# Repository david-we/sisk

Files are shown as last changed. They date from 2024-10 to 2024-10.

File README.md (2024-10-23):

# SiSK 
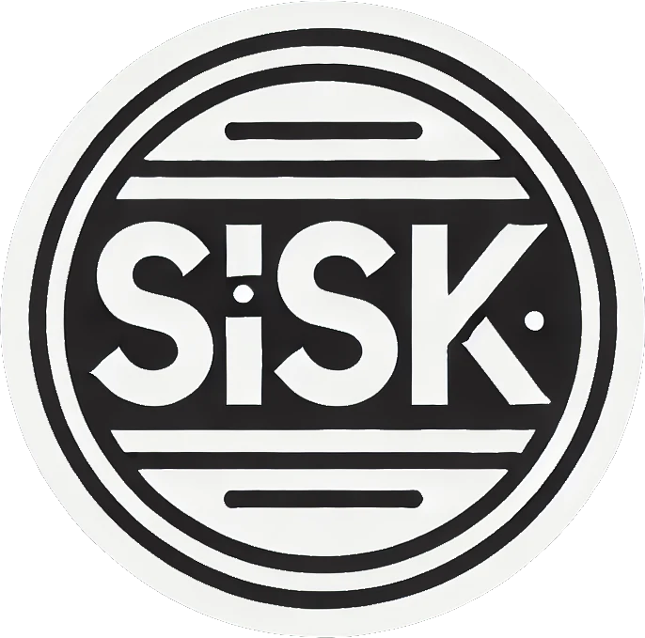
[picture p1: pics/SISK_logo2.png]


**THIS IS STILL WORK IN PROGRESS !**  

SiSK is a split keyboard with focus on standard staggered ISO Layout. it is an opportunity for those that do not want to jump on the ortholinear bandwagon, but still want to have the ergonomic advantages of a split keyboard. There will be a 60% version and a 65% Version of the PCB (which is already in the making). 

The plan is it starts as a base PCB which can then be easily used for DIY 3D-printed case designs. I am also planing to experiment with different case mounting techniques like top mount, sandwich mount, tray mount, gasket mount...

SiSK is meant as a wireless keyboard and my first prototype will use nice!nano v2 compatible Microcontroller boards and el cheapo 128x32 i2C displays for monitoring the battery...

## naming
**S**plit **I**SO **S**taggered **K**eyboard  
i know very ingenious :sweat_smile: but it was a very quick decision and AI created a logo that i liked, so its fine!

## features

- split
- ISO
- staggered
- wireless
- screw on wrist/palm wrest
- 128x32 OLED Display (I2C)
- 60% and 65% Version available
- first case will probably also use a foldable tenting solution (chinese mini Laptop stands)

### why?

I know there are similar keyboards out there, in fact there are also kits available that are in the same category. But still i was not satisfied with the existing solutions. Some where also hard to get in europe or had no ISO Layout. Another big point for me was the learning aspect, especially KiCAD and SMD soldering. AND i want a detachable solution for palm rests.

## pics

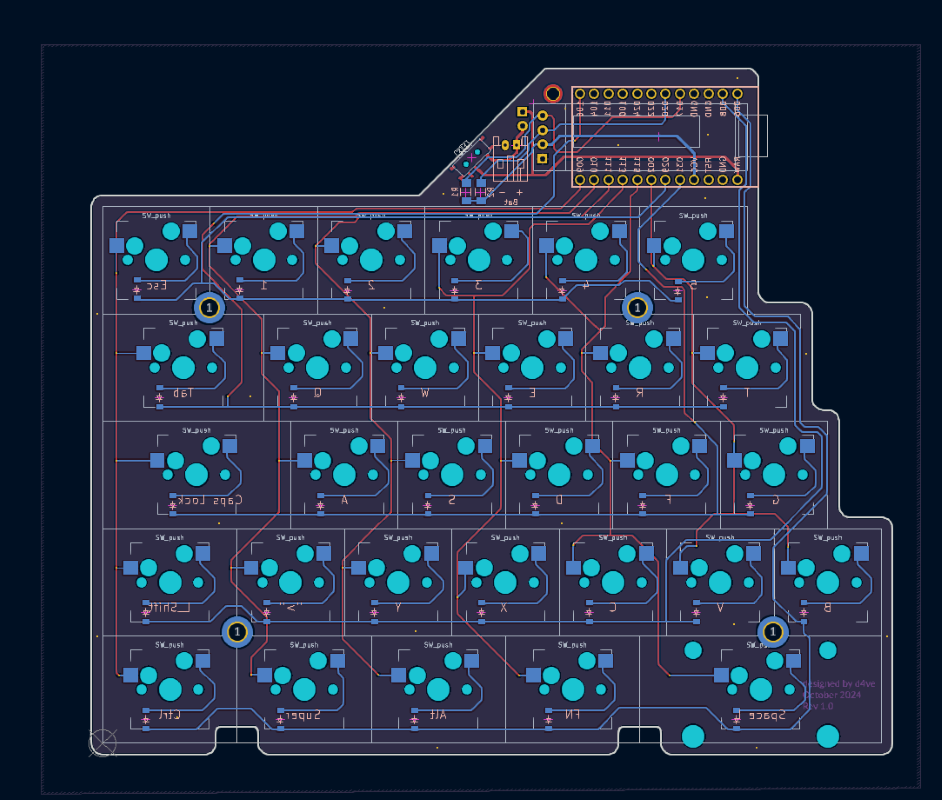
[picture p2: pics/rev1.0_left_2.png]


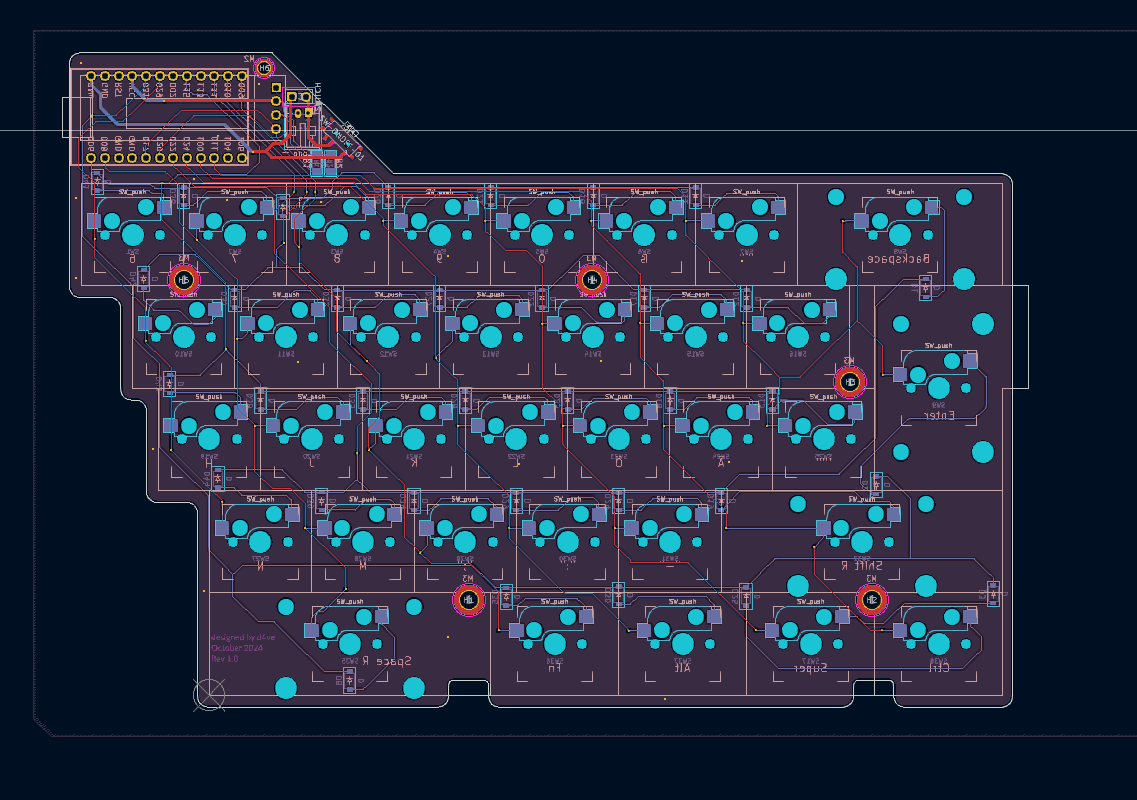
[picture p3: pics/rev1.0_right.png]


### history

last year i made this thing, which is kind of the predecessor of SiSK. But handwired and driven by a raspberry pi pico. It worked very well but the connector between the two halves sometimes looses contact. then i have to wobble around on the connector and it works again :P ... otherwise it worked flawless  

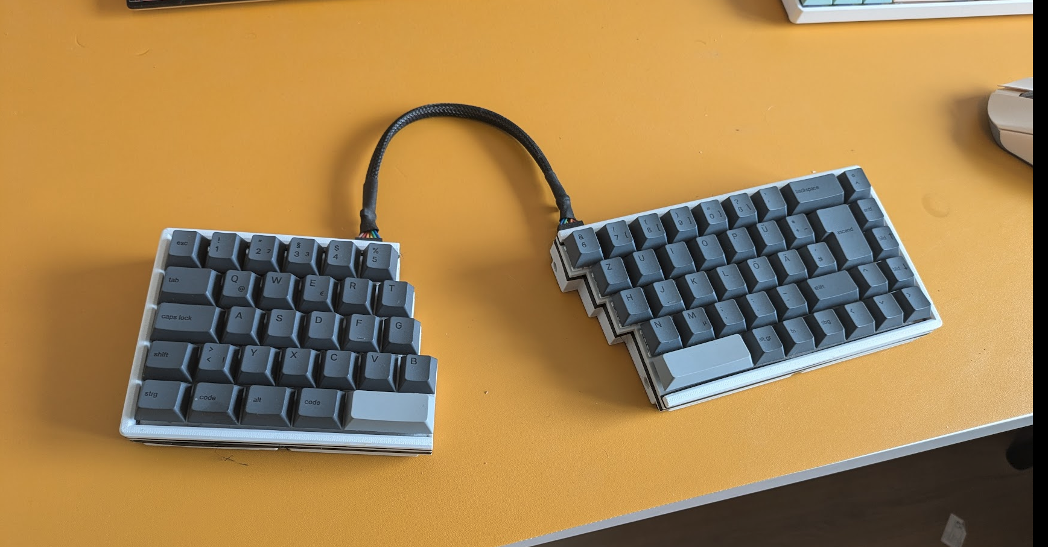
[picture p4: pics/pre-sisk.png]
sisk


## next steps

waiting for PCBs :) 

## ideas for future

- ANSI layout

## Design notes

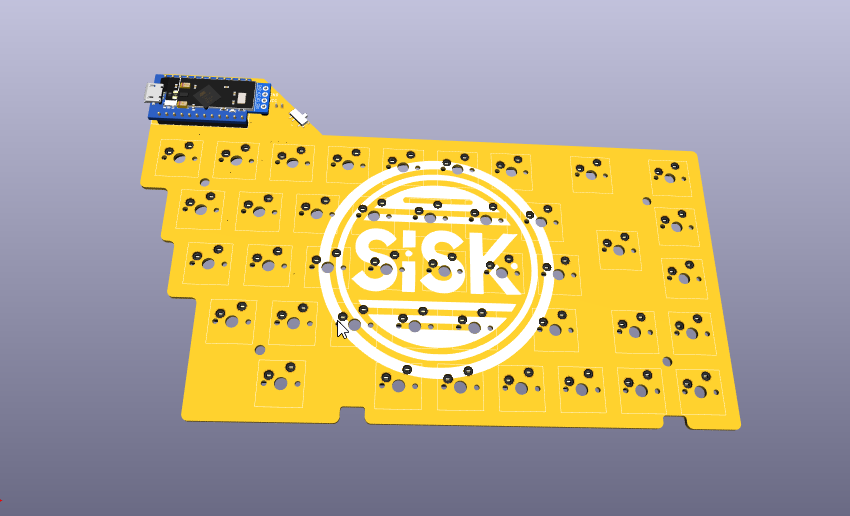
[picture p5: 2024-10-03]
pics/right_sisk_3d.png

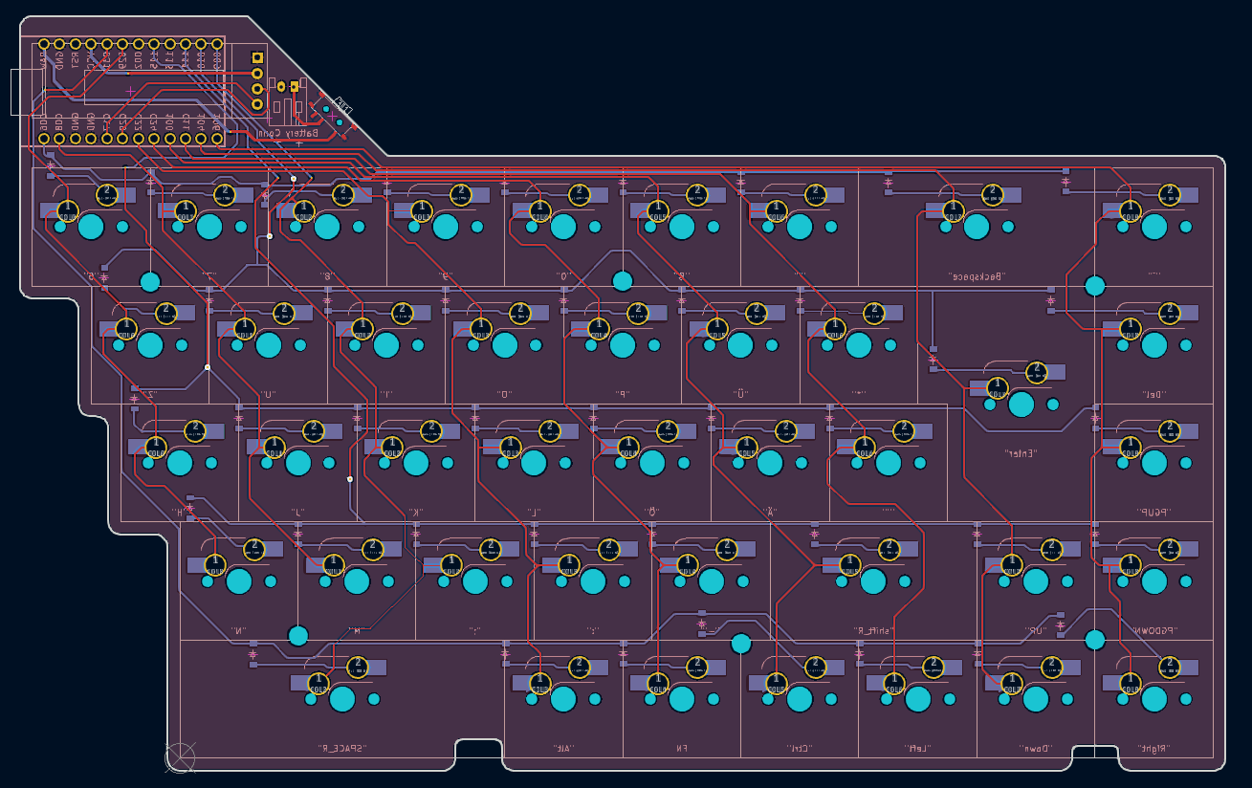
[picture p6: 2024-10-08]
pics/right_pcb_routing.png

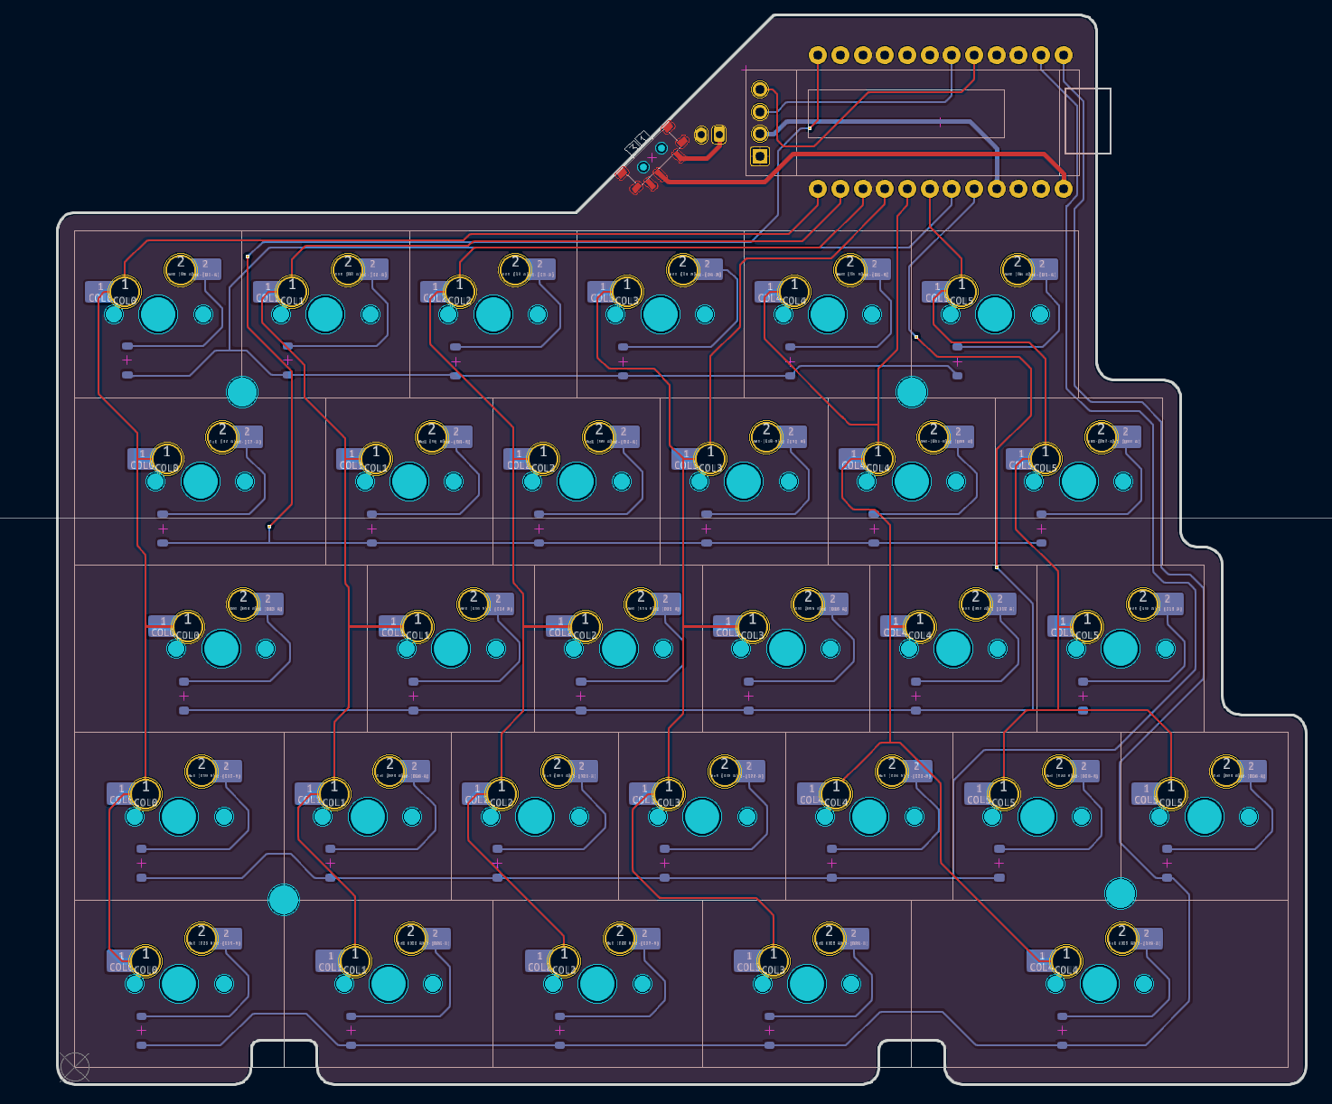
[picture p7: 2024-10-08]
pics/left_pcb_routing.PNG

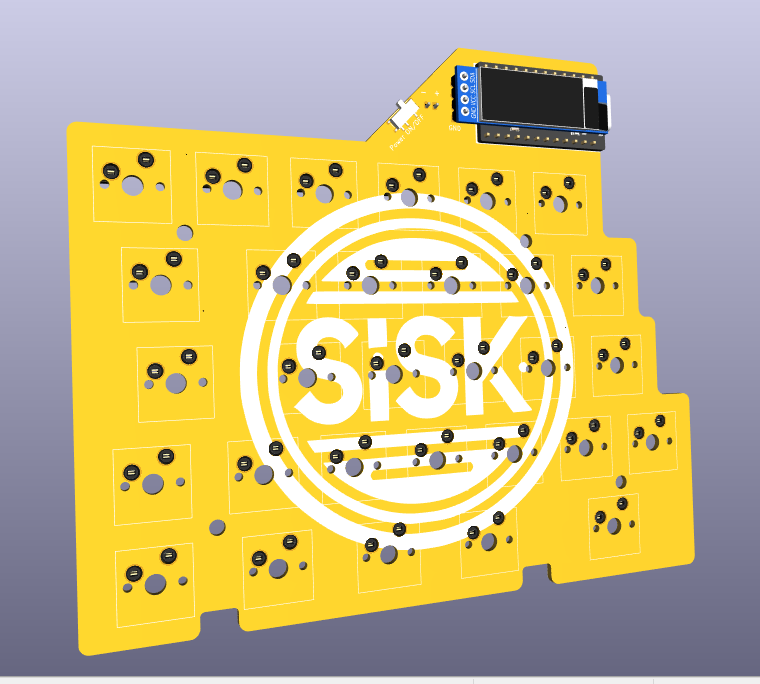
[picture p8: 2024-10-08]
pics/left_pcb_3d_front.PNG

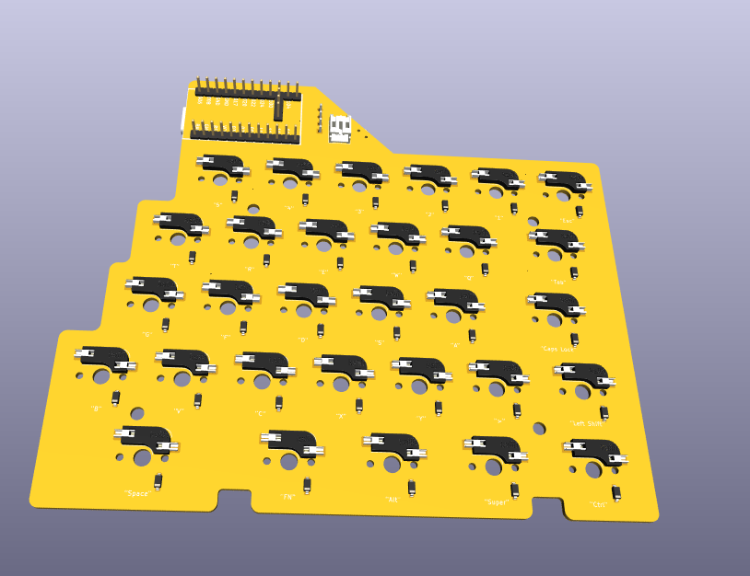
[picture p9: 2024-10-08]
pics/left_pcb_3d_back.PNG

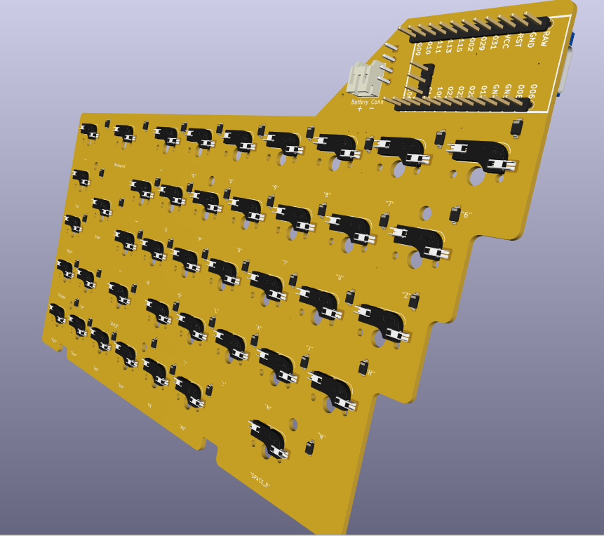
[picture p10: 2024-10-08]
pics/right_pcb_3d_back.PNG

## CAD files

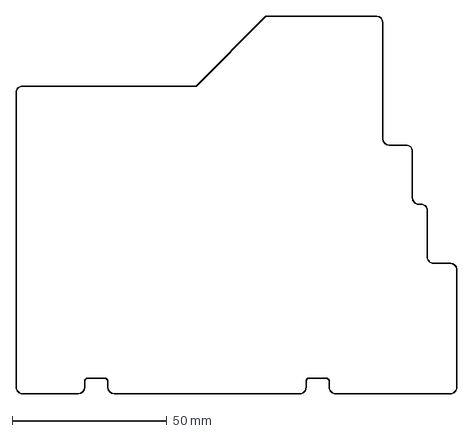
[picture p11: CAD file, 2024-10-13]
SISK_left/outline_left_w_cutouts2.dxf
142.1 x 121.7 mm

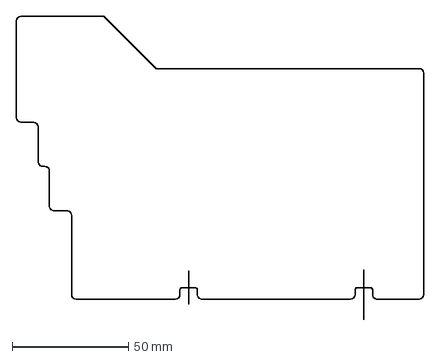
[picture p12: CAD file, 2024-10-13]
SISK_right_60/outline_right_w_cutouts_1mm.dxf
175.5 x 130.6 mm

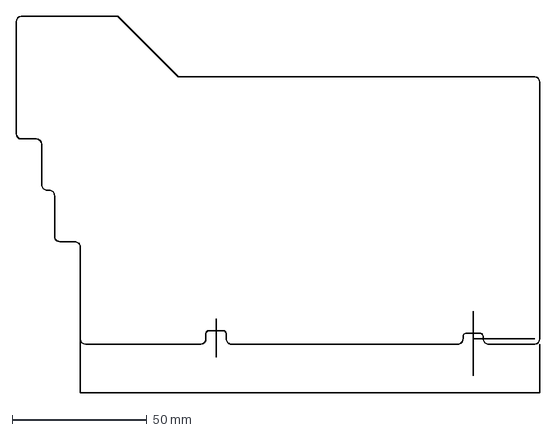
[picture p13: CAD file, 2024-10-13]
SISK_right_65/outline_right_w_cutouts2.dxf
194.5 x 139.8 mm

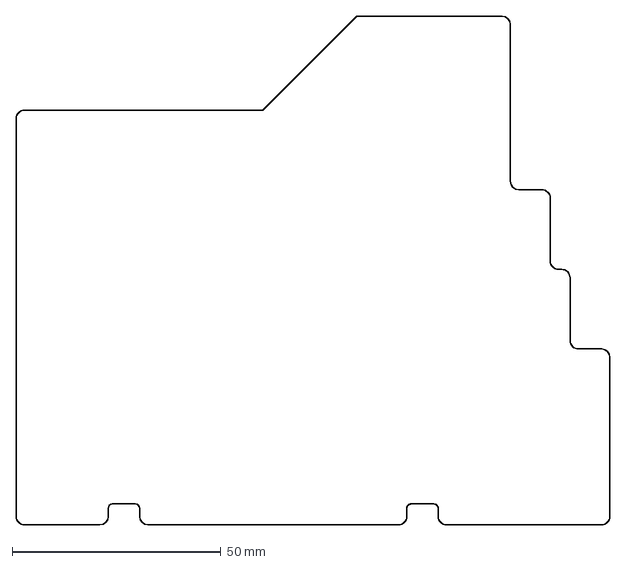
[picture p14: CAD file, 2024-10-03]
SISK_left/outline_left_w_cutouts.dxf
142.1 x 121.7 mm

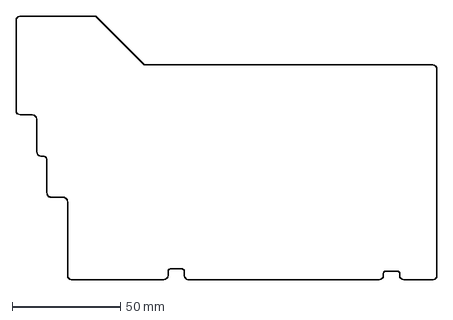
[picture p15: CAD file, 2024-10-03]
SISK_right_60/outline_right_w_cutouts.dxf
194.5 x 121.8 mm

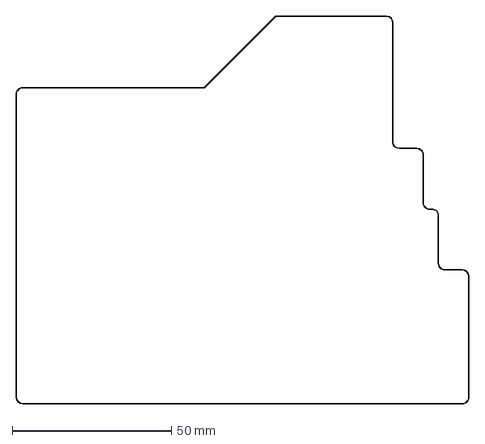
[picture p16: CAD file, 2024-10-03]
SISK_left/outline_left.dxf
142.1 x 121.7 mm

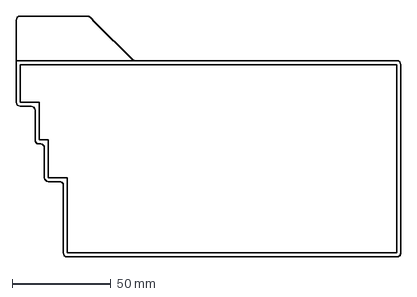
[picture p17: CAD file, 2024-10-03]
SISK_right_60/outline.dxf
194.5 x 121.8 mm

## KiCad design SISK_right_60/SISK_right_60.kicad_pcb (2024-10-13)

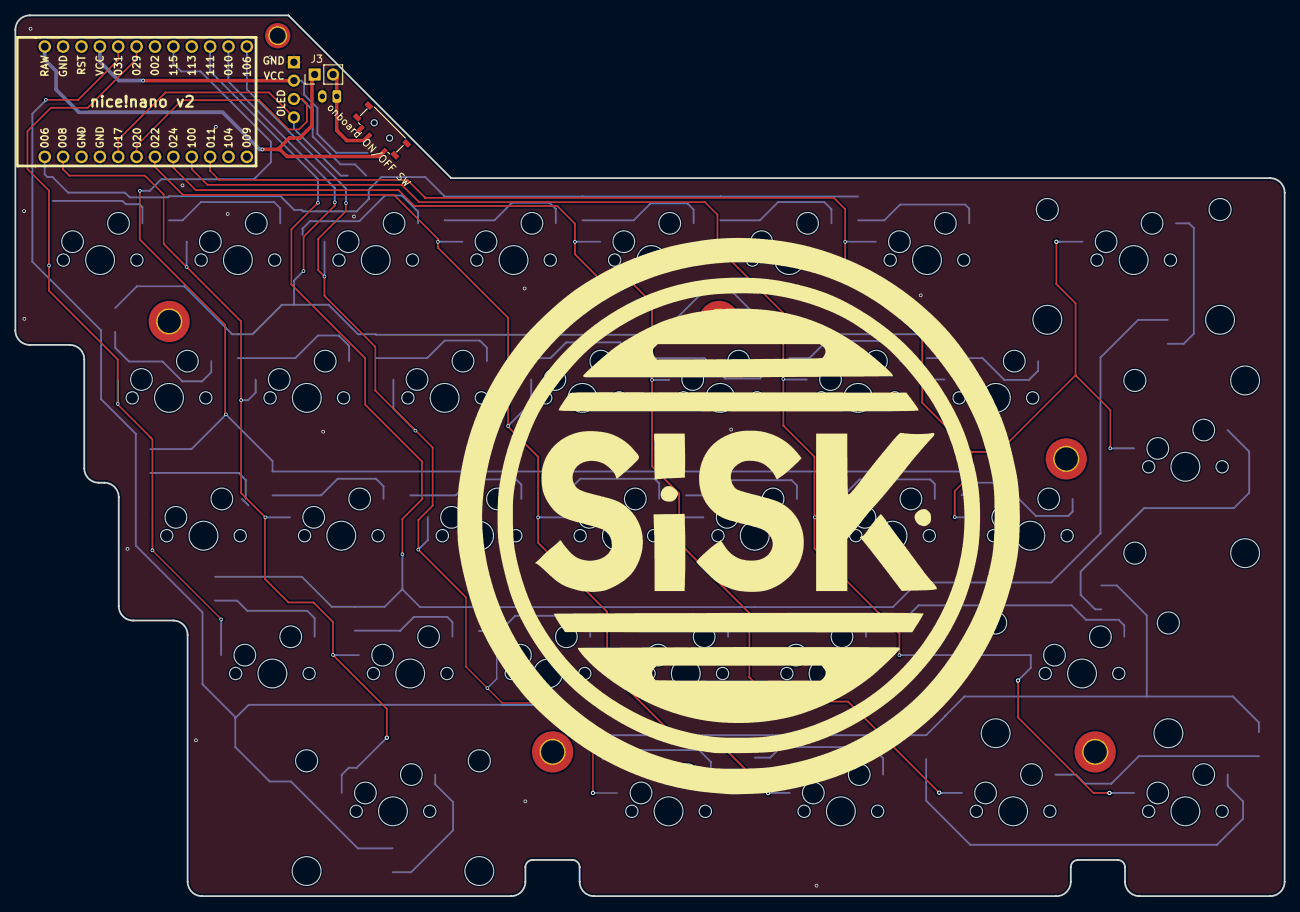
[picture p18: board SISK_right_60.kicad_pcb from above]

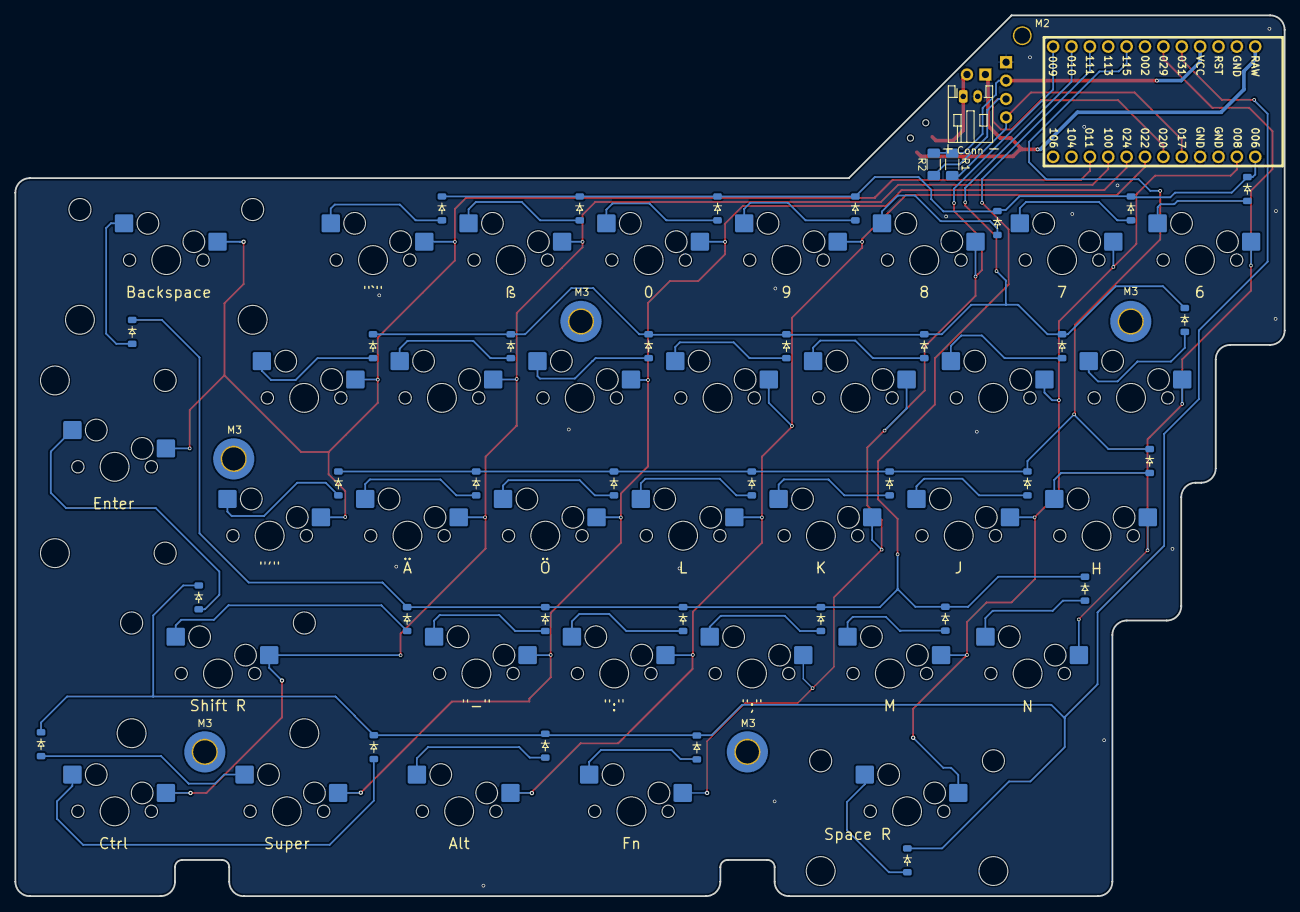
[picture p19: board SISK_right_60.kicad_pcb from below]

Board: 2 copper layers, 175.4 x 121.8 mm, 81 parts (71 on the bottom side), 52 nets.

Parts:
D1, D2, D3, D8, D11, D12, D13, D16, D17, D18, D19, D21, D22, D23, D24, D25, D26, D27, D28, D29, D30, D31, D32, D33, D34, D35, D36, D37, D38, D39, D41, D42, D43, D44: D; Diode_SOD-123
H1, H2, H3, H4, H5: M3; MountingHole_3.2mm_M3_ISO7380_Pad_TopBottom
H6: M2; MountingHole_2.2mm_M2_ISO7380_Pad_TopOnly
J1: OLED_128x32
J2: Conn; JST_PH_S2B-PH-K_1x02_P2.00mm_Horizontal
J3: SWITCH; PinHeader_1x02_P2.54mm_Vertical
R1, R2: 5K; R_1206_3216Metric_Pad1.30x1.75mm_HandSolder
SW1, SW2, SW3, SW4, SW5, SW6, SW7, SW10, SW11, SW12, SW13, SW14, SW15, SW16, SW19, SW20, SW21, SW22, SW23, SW24, SW25, SW27, SW28, SW29, SW30, SW31: SW_push; MX-Hotswap-1U
SW8: SW_push; MX-Hotswap-2U
SW9: SW_push; MX-Hotswap-ISO
SW17, SW36, SW37, SW38: SW_push; MX-Hotswap-1.25U
SW32, SW35: SW_push; MX-Hotswap-2.75U
SW-ONOFF-01: Switch_MSK12C02
U1: Nice_Nano_V2; nice_nano

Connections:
+3,3V: J1.2 (VCC), R1.1, R2.1, U1.21 (3.3v)
+BATT: J2.1, J3.2, SW-ONOFF-01.2 (B)
+VDC: J3.1, SW-ONOFF-01.1 (A), U1.24 (B+)
/COL0: SW1.1, SW10.1, SW19.1, SW27.1, U1.19 (20)
/COL1: SW2.1, SW11.1, SW20.1, SW28.1, SW35.1, U1.2 (0)
/COL2: SW3.1, SW12.1, SW21.1, SW29.1, SW36.1, U1.13 (10)
/COL3: SW4.1, SW13.1, SW22.1, SW30.1, SW37.1, U1.7 (4)
/COL4: SW5.1, SW14.1, SW17.1, SW23.1, SW31.1, U1.8 (5)
/COL5: SW6.1, SW15.1, SW24.1, SW32.1, SW38.1, U1.9 (6)
/COL6: SW7.1, SW8.1, SW9.1, SW16.1, SW25.1, U1.10 (7)
/ROW0: D11.1 (K), D16.1 (K), D21.1 (K), D26.1 (K), D31.1 (K), D36.1 (K), D41.1 (K), U1.1
/ROW1: D12.1 (K), D17.1 (K), D22.1 (K), D27.1 (K), D32.1 (K), D37.1 (K), D42.1 (K), U1.14 (16)
/ROW2: D13.1 (K), D18.1 (K), D23.1 (K), D28.1 (K), D33.1 (K), D38.1 (K), D43.1 (K), U1.17 (18)
/ROW3: D1.1 (K), D19.1 (K), D24.1 (K), D29.1 (K), D34.1 (K), D39.1 (K), D44.1 (K), U1.15 (14)
/ROW4: D2.1 (K), D3.1 (K), D8.1 (K), D25.1 (K), D30.1 (K), D35.1 (K), U1.20 (21)
/SCL: J1.3 (SCL), R2.2, U1.6 (3)
/SDA: J1.4 (SDA), R1.2, U1.5 (2)
GND: J1.1 (GND), J2.2, U1.3 (GND), U1.4 (GND), U1.23 (GND)
unnamed: D1.2 (A), SW8.2
unnamed: D2.2 (A), SW9.2
unnamed: D3.2 (A), SW17.2
unnamed: D8.2 (A), SW35.2
unnamed: D11.2 (A), SW7.2
unnamed: D12.2 (A), SW16.2
unnamed: D13.2 (A), SW25.2
unnamed: D16.2 (A), SW6.2
unnamed: D17.2 (A), SW15.2
unnamed: D18.2 (A), SW24.2
unnamed: D19.2 (A), SW32.2
unnamed: D21.2 (A), SW5.2
unnamed: D22.2 (A), SW14.2
unnamed: D23.2 (A), SW23.2
unnamed: D24.2 (A), SW31.2
unnamed: D25.2 (A), SW38.2
unnamed: D26.2 (A), SW4.2
unnamed: D27.2 (A), SW13.2
unnamed: D28.2 (A), SW22.2
unnamed: D29.2 (A), SW30.2
unnamed: D30.2 (A), SW37.2
unnamed: D31.2 (A), SW3.2
unnamed: D32.2 (A), SW12.2
unnamed: D33.2 (A), SW21.2
unnamed: D34.2 (A), SW29.2
unnamed: D35.2 (A), SW36.2
unnamed: D36.2 (A), SW2.2
unnamed: D37.2 (A), SW11.2
unnamed: D38.2 (A), SW20.2
unnamed: D39.2 (A), SW28.2
unnamed: D41.2 (A), SW1.2
unnamed: D42.2 (A), SW10.2
unnamed: D43.2 (A), SW19.2
unnamed: D44.2 (A), SW27.2

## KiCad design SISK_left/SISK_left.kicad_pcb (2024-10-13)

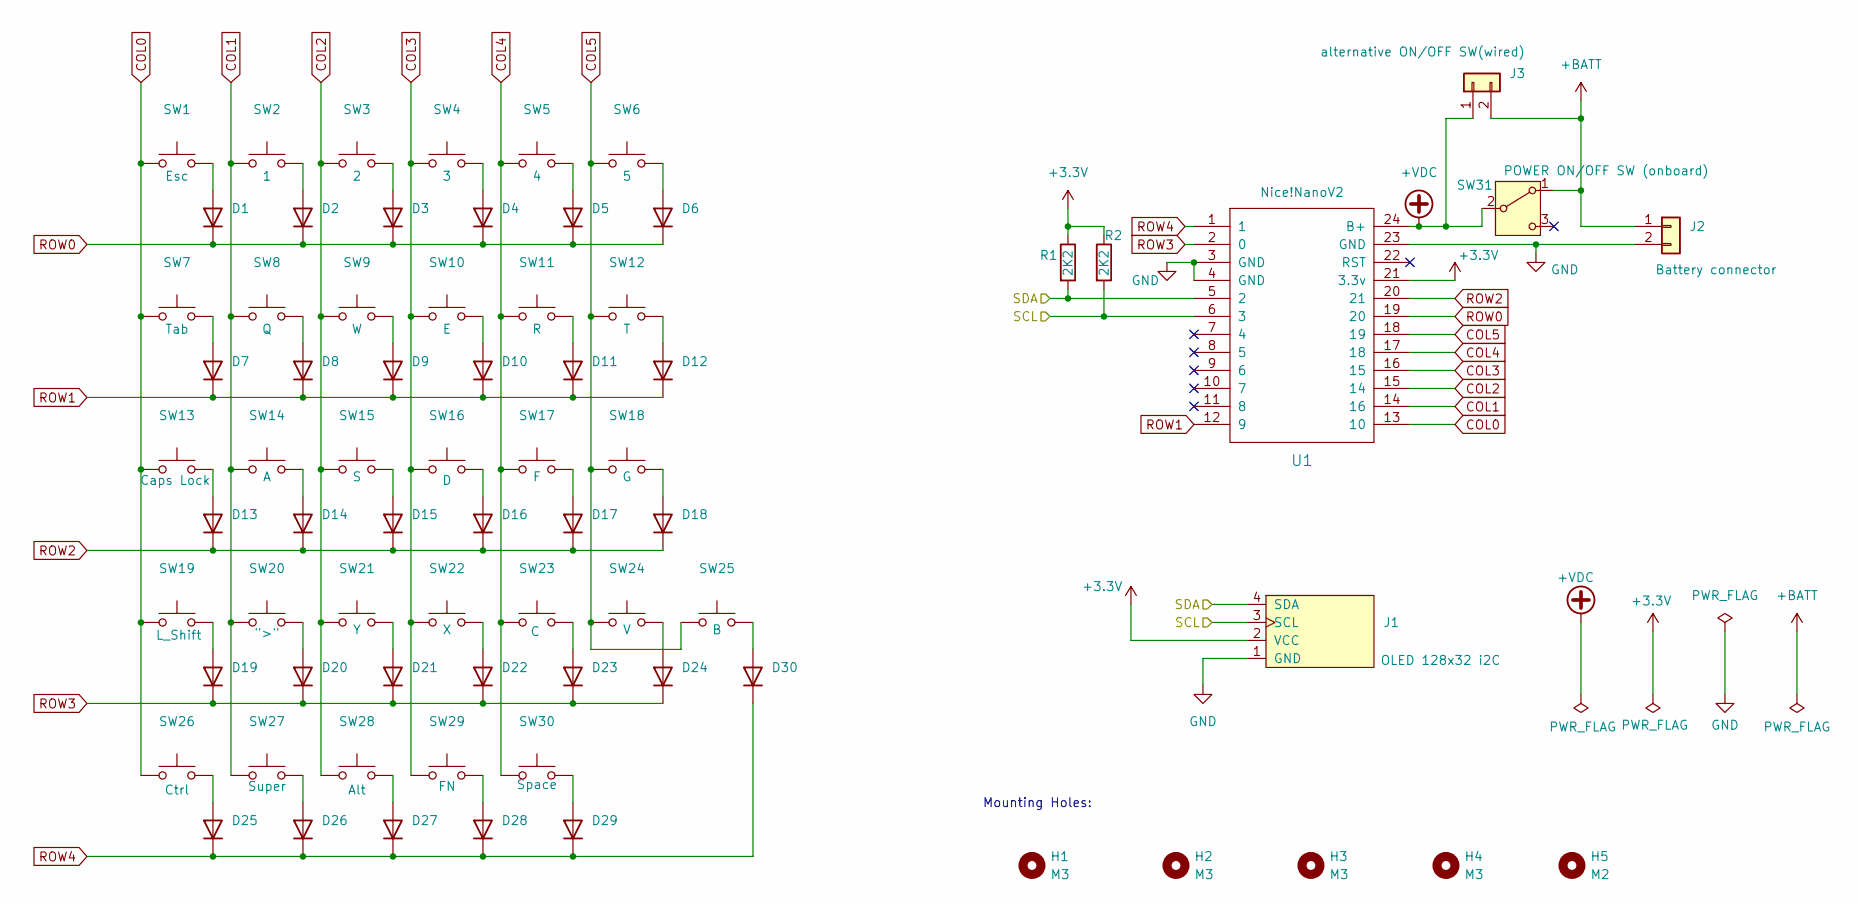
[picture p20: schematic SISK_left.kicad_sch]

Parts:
D1, D2, D3, D4, D5, D6, D7, D8, D9, D10, D11, D12, D13, D14, D15, D16, D17, D18, D19, D20, D21, D22, D23, D24, D25, D26, D27, D28, D29, D30: 1n4148; Diode_SOD-123; MPN 1N4148W
H1, H2, H3, H4: M3; MountingHole_3.2mm_M3_ISO7380_Pad_TopBottom
H5: M2; MountingHole_2.2mm_M2_ISO7380_Pad_TopOnly
J1: OLED_128x32; MPN OLED 128x32 i2C
J2: BAT; JST_PH_S2B-PH-K_1x02_P2.00mm_Horizontal; MPN S2B-PH-K-S(LF)(SN)
J3: CONN_ALT; PinHeader_1x02_P2.54mm_Vertical; MPN not known yet
R1, R2: 2K2; R_1206_3216Metric_Pad1.30x1.75mm_HandSolder; MPN RC1206JR-072K2L
SW1, SW2, SW3, SW4, SW5, SW6, SW8, SW9, SW10, SW11, SW12, SW14, SW15, SW16, SW17, SW18, SW20, SW21, SW22, SW23, SW24, SW25: SW_push; MX-Hotswap-1U; MPN CPG151101S11
SW7: SW_push; MX-Hotswap-1.5U; MPN CPG151101S11
SW13: SW_push; MX-Hotswap-1.75U; MPN CPG151101S11
SW19, SW26, SW27, SW28, SW29: SW_push; MX-Hotswap-1.25U; MPN CPG151101S11
SW30: SW_push; MX-Hotswap-2.25U; MPN CPG151101S11
SW31: SW_SPDT; Switch_MSK12C02; MPN MSK12C01
U1: Nice_Nano_V2; nice_nano; MPN nice!nano v2 or compatible

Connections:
+3.3V: J1.2 (VCC), R1.1, R2.1, U1.21 (3.3v)
+BATT: J2.1, J3.2, SW31.1 (A)
+VDC: J3.1, SW31.2 (B), U1.24 (B+)
/SCL: J1.3 (SCL), R2.2, U1.6 (3)
/SDA: J1.4 (SDA), R1.2, U1.5 (2)
COL0: SW1.1, SW7.1, SW13.1, SW19.1, SW26.1, U1.13 (10)
COL1: SW2.1, SW8.1, SW14.1, SW20.1, SW27.1, U1.14 (16)
COL2: SW3.1, SW9.1, SW15.1, SW21.1, SW28.1, U1.15 (14)
COL3: SW4.1, SW10.1, SW16.1, SW22.1, SW29.1, U1.16 (15)
COL4: SW5.1, SW11.1, SW17.1, SW23.1, SW30.1, U1.17 (18)
COL5: SW6.1, SW12.1, SW18.1, SW24.1, SW25.1, U1.18 (19)
GND: J1.1 (GND), J2.2, U1.3 (GND), U1.4 (GND), U1.23 (GND)
unnamed: D1.2 (A), SW1.2
unnamed: D2.2 (A), SW2.2
unnamed: D3.2 (A), SW3.2
unnamed: D4.2 (A), SW4.2
unnamed: D5.2 (A), SW5.2
unnamed: D6.2 (A), SW6.2
unnamed: D7.2 (A), SW7.2
unnamed: D8.2 (A), SW8.2
unnamed: D9.2 (A), SW9.2
unnamed: D10.2 (A), SW10.2
unnamed: D11.2 (A), SW11.2
unnamed: D12.2 (A), SW12.2
unnamed: D13.2 (A), SW13.2
unnamed: D14.2 (A), SW14.2
unnamed: D15.2 (A), SW15.2
unnamed: D16.2 (A), SW16.2
unnamed: D17.2 (A), SW17.2
unnamed: D18.2 (A), SW18.2
unnamed: D19.2 (A), SW19.2
unnamed: D20.2 (A), SW20.2
unnamed: D21.2 (A), SW21.2
unnamed: D22.2 (A), SW22.2
unnamed: D23.2 (A), SW23.2
unnamed: D24.2 (A), SW24.2
unnamed: D25.2 (A), SW26.2
unnamed: D26.2 (A), SW27.2
unnamed: D27.2 (A), SW28.2
unnamed: D28.2 (A), SW29.2
unnamed: D29.2 (A), SW30.2
unnamed: D30.2 (A), SW25.2
ROW0: D1.1 (K), D2.1 (K), D3.1 (K), D4.1 (K), D5.1 (K), D6.1 (K), U1.19 (20)
ROW1: D7.1 (K), D8.1 (K), D9.1 (K), D10.1 (K), D11.1 (K), D12.1 (K), U1.12 (9)
ROW2: D13.1 (K), D14.1 (K), D15.1 (K), D16.1 (K), D17.1 (K), D18.1 (K), U1.20 (21)
ROW3: D19.1 (K), D20.1 (K), D21.1 (K), D22.1 (K), D23.1 (K), D24.1 (K), U1.2 (0)
ROW4: D25.1 (K), D26.1 (K), D27.1 (K), D28.1 (K), D29.1 (K), D30.1 (K), U1.1

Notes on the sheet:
Mounting Holes:

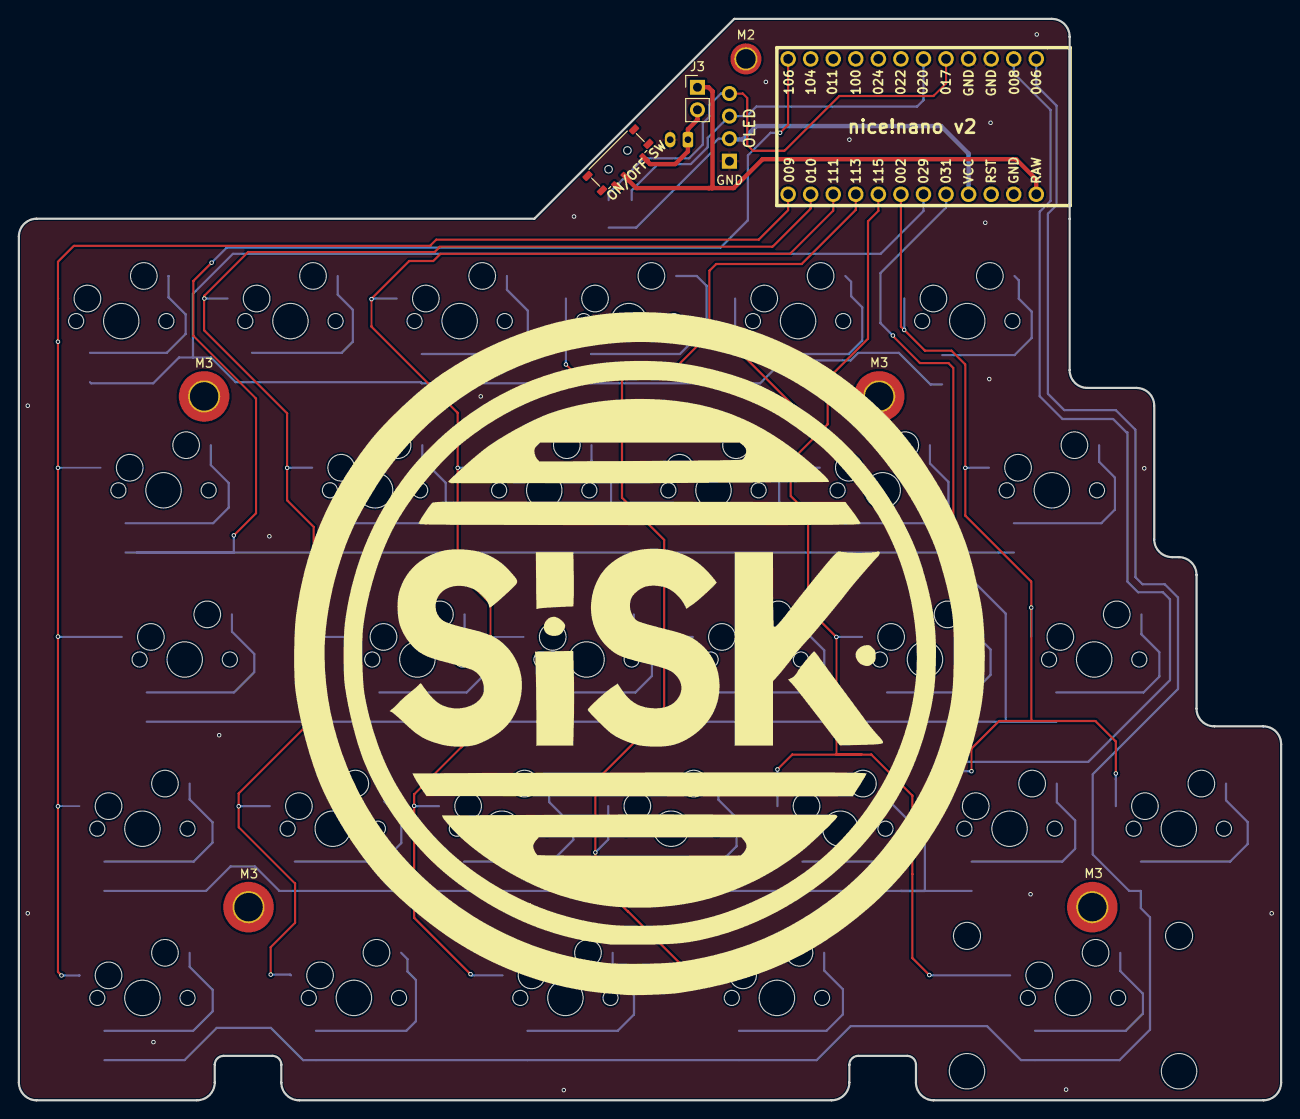
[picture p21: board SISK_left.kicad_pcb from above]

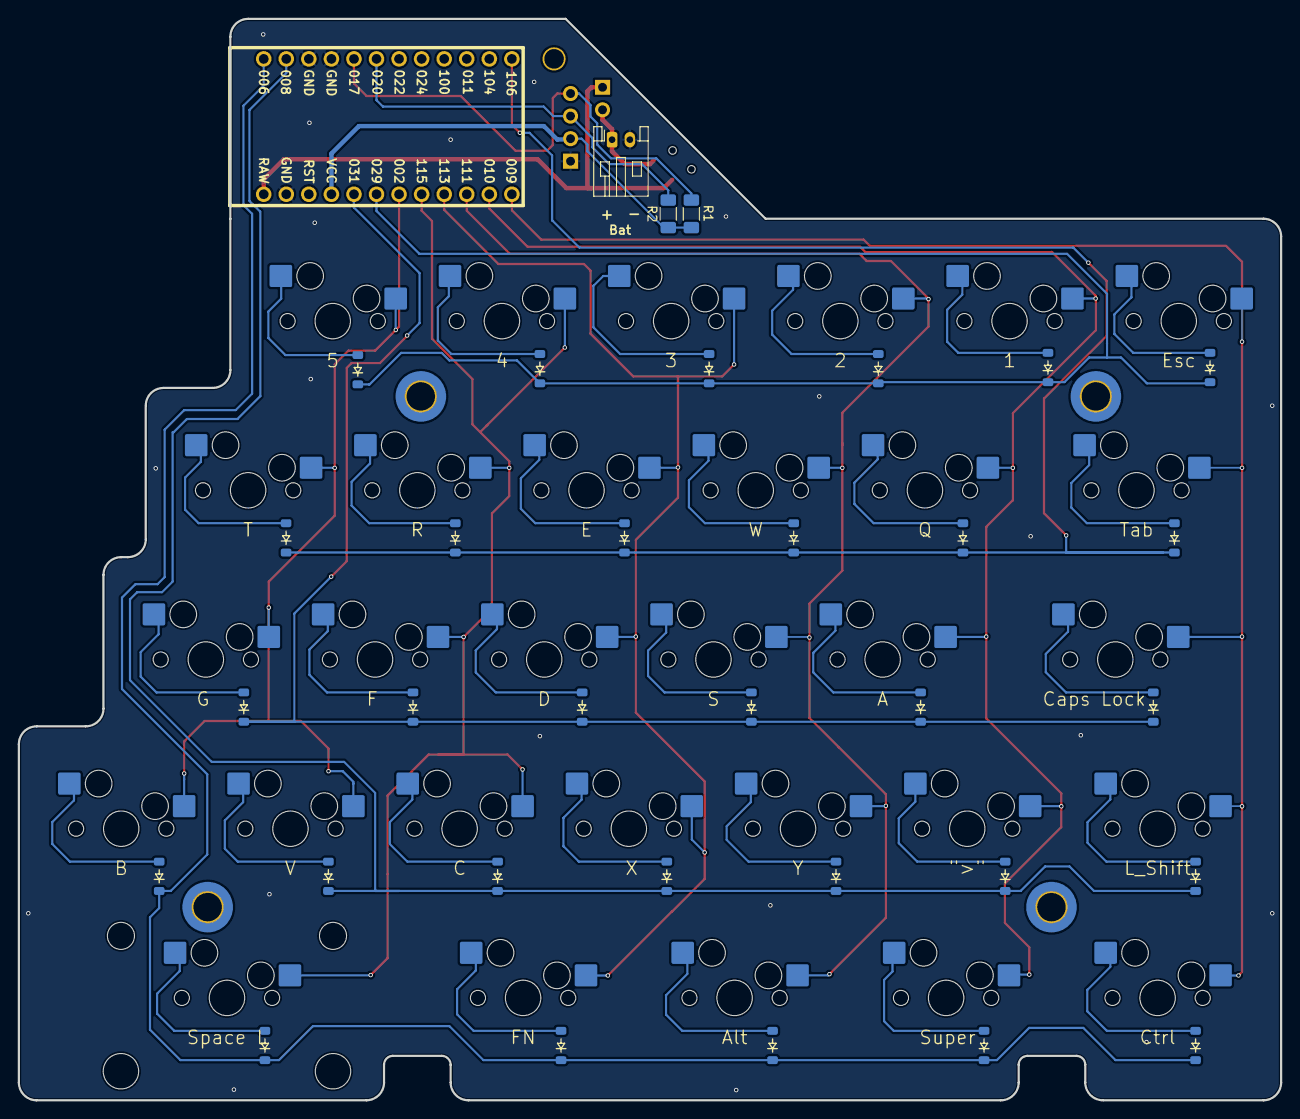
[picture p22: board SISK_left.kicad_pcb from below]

Board: 2 copper layers, 142.1 x 121.8 mm, 72 parts (63 on the bottom side), 47 nets.

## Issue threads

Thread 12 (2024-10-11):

Lock placed footprints to avoid accidental move

christandlg, 2024-10-11:
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

david-we, 2024-10-12:
done

Closed 2024-10-12.

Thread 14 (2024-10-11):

hotswap socket: does not match manufacturer recommended footprint

christandlg, 2024-10-11:
https://wmsc.lcsc.com/wmsc/upload/file/pdf/v2/lcsc/2211090930_Kailh-CPG151101S11-1_C5184526.pdf
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

PTH should be NPTH - plastic part through hole
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

SMD pads should not extend to hole

this may also fix DRC clearance violations
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

Closed 2024-10-11.

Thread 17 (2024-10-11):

Nice_Nano_V2 Pins 25, 26, 27 missing from Footprint

christandlg, 2024-10-11:
should be removed from schematic symbol as well or DRC will complain

david-we, 2024-10-11:
done

Closed 2024-10-11.

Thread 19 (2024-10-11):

keep components on one side

christandlg, 2024-10-11:
e.g. all SMD components on bot. might reduce assembly costs.

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

david-we, 2024-10-11:
no automatic assembly planed yet, the on/off switch would be on a diffrent place then, which i am not sure would fit with the case i have in mind...

Closed 2024-10-11.

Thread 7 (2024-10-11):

Nice_Nano_V2 GPIOs should be Bidirectional

christandlg, 2024-10-11:
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
this will also clear Input pin not driven by any Output pins" ERC Error

david-we, 2024-10-11:
done

Closed 2024-10-11.

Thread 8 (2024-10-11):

I2C Pullups

christandlg, 2024-10-11:
add pullups to I2C SCL and SDA Lines (~2.2k is good). footprints may stay unpolulated if Nano V2or OLED contains pullups.
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

david-we, 2024-10-11:
nicenano should contain internal pullups, anyway i integrated the pads to be sure.

https://devzone.nordicsemi.com/f/nordic-q-a/68167/internal-pull-up-on-i2c-bus
https://www.reddit.com/r/zmk/comments/160l9ur/help_zmk_nicenano_v2_with_an_i2c_128x32_oled_oled/

Closed 2024-10-11.

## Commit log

2024-10-07 changes after first review
    [SISK_left.kicad_pcb, SISK_right.kicad_pcb]
2024-10-08 changed nice nano footprint
    [SISK_left.kicad_pcb, SISK_left.kicad_sch, SISK_right.kicad_pcb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]
2024-10-09 added some text and alternative header for Power Switch
    [SISK_left.kicad_pcb, SISK_left.kicad_sch, SISK_right.kicad_pcb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]
2024-10-11 changed file structure, added new project for 60%, changed main footprints for hotswap sockets
    [SISK_left.kicad_pcb, SISK_left.kicad_sch, SISK_right.kicad_pcb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]
2024-10-11 fixed schematics, added optional pullup resistors
    [SISK_left.kicad_pcb, SISK_left.kicad_sch, SISK_right_65.kicad_pcb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]
2024-10-12 fixed some issues
    [SISK_left.kicad_pcb, SISK_right_65.kicad_pcb, SISK_right_65.kicad_sch]
2024-10-13 fixed most of issues, updated 60% version
    [SISK_left.kicad_pcb, SISK_left.kicad_sch, SISK_right_60.kicad_pcb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]
2024-10-13 improved the whole mounting hole situation
    [SISK_left.kicad_pcb, SISK_left.kicad_sch, SISK_right_60.kicad_pcb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]
2024-10-13 last changes on silkscreen before manufaturing
    [SISK_left.kicad_pcb, SISK_right_60.kicad_pcb, SISK_right_60.kicad_sch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]
2024-10-13 add logo with transparent background
    [outline_left_w_cutouts2.dxf, outline_right_w_cutouts2.dxf]
